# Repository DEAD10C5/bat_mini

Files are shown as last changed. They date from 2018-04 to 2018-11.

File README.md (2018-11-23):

# Bat Badge 2018  



## Serial

You can make a serial connection to the badge using a USB to TTL serial cable. 

For example: 
[USB to TTL Serial Cable](https://www.adafruit.com/product/954)

- Green wire: Connect to serial port, right side looking at back. 
- White wire: Connect to serial port, left side looking at back.
- Black wire: Connect to Battery port, negative (-) port. 
- Red/Orange wire: Do not connect! This is +5V but the board is at +3V. 

## Programming 

We used an Arduino UNO as an ISP to program the attiny84 chip on the badge. 

[Set up the programming environment](http://highlowtech.org/?p=1695)

We did a "6 way" header similar to the one described at the link below. 

[About ISP headers](http://www.batsocks.co.uk/readme/isp_headers.htm)

## Chip Information

ATMEL ATTINY84 / ARDUINO pinout

````
//

//                      +-\/-+

//                VCC 1|      |14 GND

//       `  (D 0) PB0 2|      |13 AREF (D10)

//          (D 1) PB1 3|      |12 PA1 (D9) 

//                PB3 4|      |11 PA2 (D 8) 

// PWM INT0 (D 2) PB2 5|      |10 PA3 (D 7) 

//      PWM (D 3) PA7 6|      |9 PA4(D 6) 

//      PWM (D 4) PA6 7|      |8 PA5(D 5) PWM

//                      +----+

IDE Attiny84 Physical Pin  Usage
  0      PA0           13  Button
  1      PA1           12  Heart
  2      PA2           11  RGB LED Data Pin
  3      PA3           10  Serial TX
  4      PA4            9
  5      PA5            8  Left Eye
  6      PA6            7  Right Eye
  7      PA7            6
  8      PB2            5
  9      PB1            3  Serial RX 
 10      PB0            2     
```

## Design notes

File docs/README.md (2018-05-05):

* http://42bots.com/tutorials/programming-attiny84-attiny44-with-arduino-uno/

# power

https://www.sparkfun.com/products/11892
https://www.sparkfun.com/products/10860

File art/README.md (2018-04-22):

# wipe the outline layer

display none 200;
group all;
delete (>0 0);
display last;
layer -200;

# import artwork

* scale art  0.0625 MM

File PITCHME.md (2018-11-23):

# Badge Workshop`

Tales From the Workbench

---

### 

- Dispatcher: Manages Data Flow
- Stores: Handle State & Logic
- Views: Render Data via React

---

Flux Explained

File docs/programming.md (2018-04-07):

* Connect a 10 uF capacitor between “Reset” and “Ground” pins on the Arduino Uno board as shown in the diagram. The stripe of the capacitor with the negative sign (“-”) goes to the Arduino “Ground” pin. This prevents the Arduino Uno from resetting and ensures that the Arduino IDE talks to the ArduinoISP (and not the bootloader) during the upload of the sketches to the ATTiny.
* Connect the ATtiny84/44 Pin 1 (with the little dot) to the 5 volt breadboard rail.
* Connect the ATtiny84/44 Pin 14 to ground.
* RESET: Connect the ATtiny84/44 Pin 4 (Reset) to Arduino Pin 10.
* MOSI: Connect the ATtiny84/44 Pin 7  to Arduino Pin 11.
* MISO: Connect the ATtiny84/44 Pin 8 to Arduino Pin 12.
* CLOCK: Connect the ATTiny84/44 Pin 9 to Arduino Pin 13
* Connect the ground and 5v from the Arduino to the breadboard.

Make sure you select the option “ATTiny84  (internal 1 MHz clock)”, or “ATTiny44  (internal 1 MHz clock)” in the Tools->Board menu (depending on which version of the chip you have):

Upload the sketch using the “File” -> “Upload Using Programmer” command (Ctrl + Shift + U).

If you get an error like this: “avrdude: please define PAGEL and BS2 signals in the configuration file…”, you can safely ignore it. This relate to parallel programmers and is not an issue here.

If all works well, you should have a blinking LED and a proven method for uploading Arduino sketches to your ATTiny84/44. Congratulations!

The next step  (Step 6) is optional. By default, the ATTiny chips run at 1 MHz. You need an extra step to configure the microcontroller to run at 8 MHz. This is a requirement for using some popular Arduino libraries, as well as to take full advantage of your chip.

To do so, you need to use the same wiring that you used to upload the blink sketch in the previous step. Under “Tools”->”Board” menu, this time select the option “ATtiny84 (internal 8 Mhz clock)”, or  “ATtiny44 (internal 8 Mhz clock)”, depending on which chip you have. It is important to pick the correct clock speed from the menu. Choosing the 20 Mhz external clock option, will require you to add wire in a 20 MHz crystal, or resonator, in order to program and use your ATTiny84/44.

Next, again under the “Tools” menu, choose the option “Burn Bootloader”. There is actually, no bootloader on the ATTiny chips, but this step will set the fuses to the values that will allow it to run at 8 Mhz, similarly to what we did for the ATtiny85 in the previous write-up.

Again, ignore any errors related to PAGEL and BS2 signals you may get. To make sure the change worked, you may want to re-upload the modified Blink sketch from step 5, this time using the internal 8 MHz clock option for your chip from the Boards menu.

Next, time to use the ATTiny in a real project! A warning: not all Arduino libraries will work on the ATTiny chips. The Arduino forum is a great place to search for additional info, if you run into issues. Chances are, someone already had this problem and found a solution.

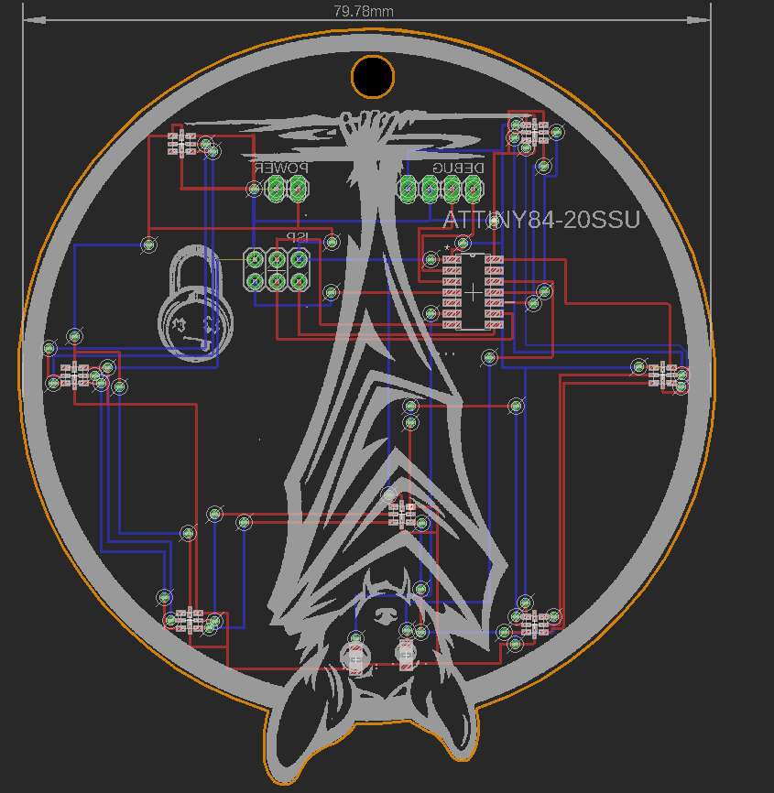
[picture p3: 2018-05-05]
art/Screenshot1.png

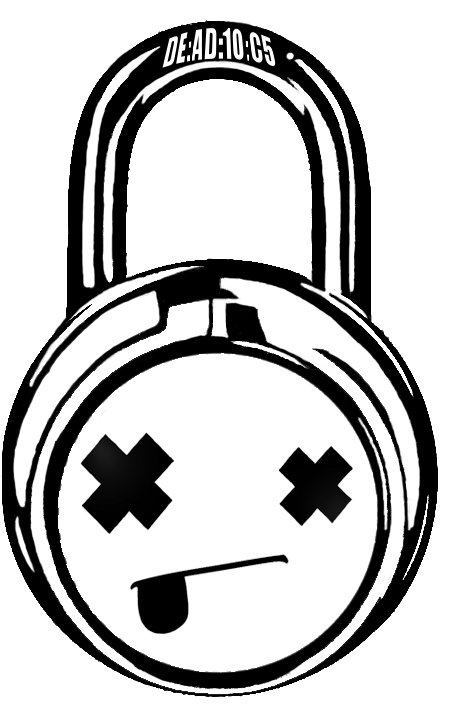
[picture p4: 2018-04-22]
art/DE:AD:10:C5-2.bmp

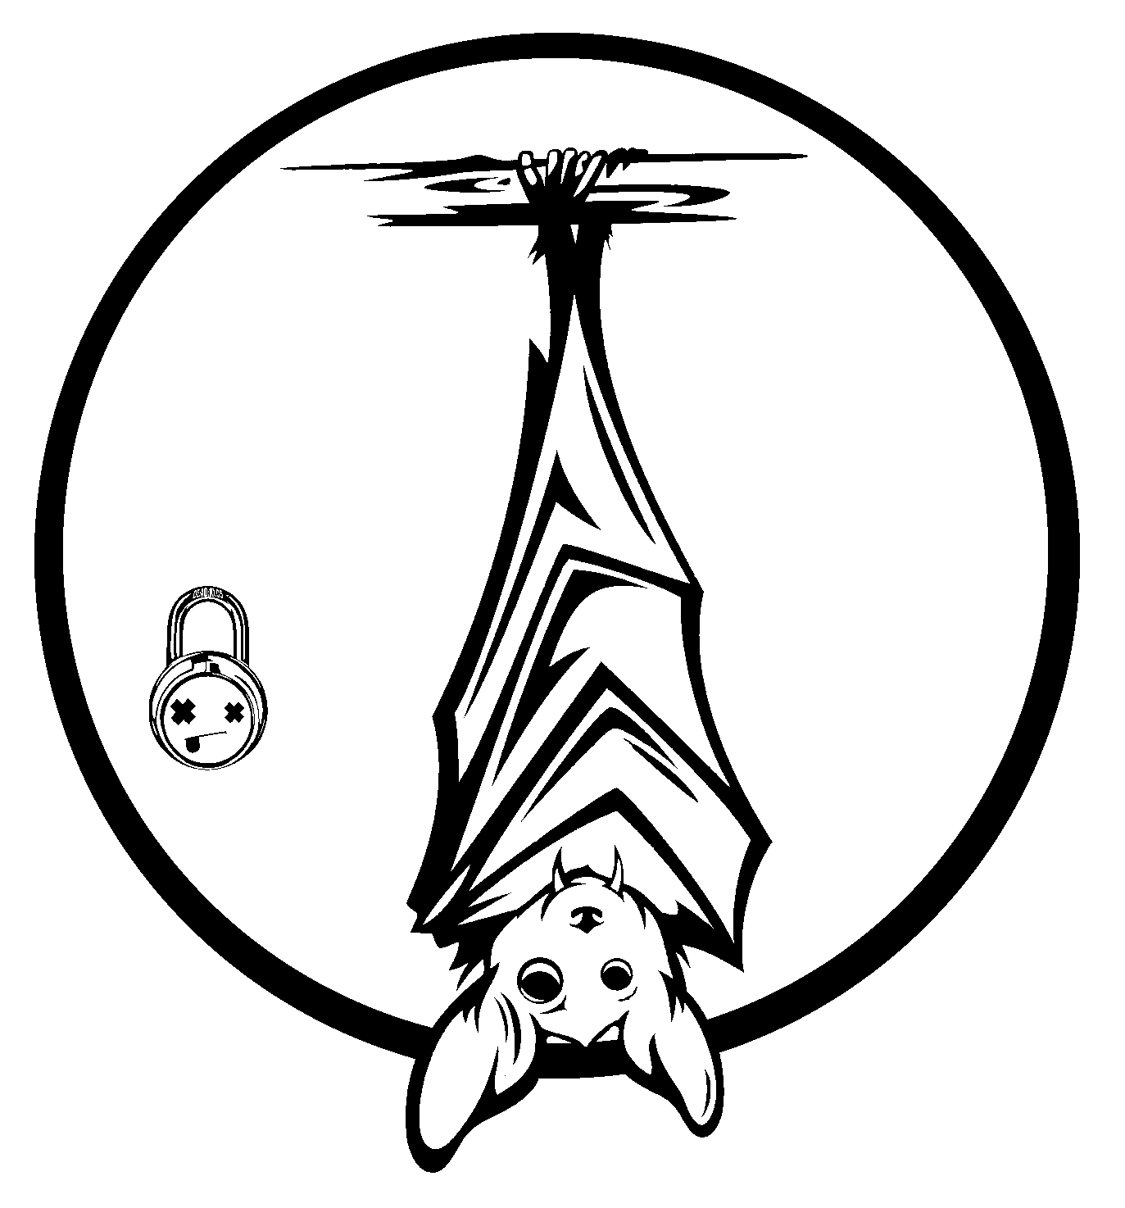
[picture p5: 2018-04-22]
art/bat_8bit_innerNEW.bmp

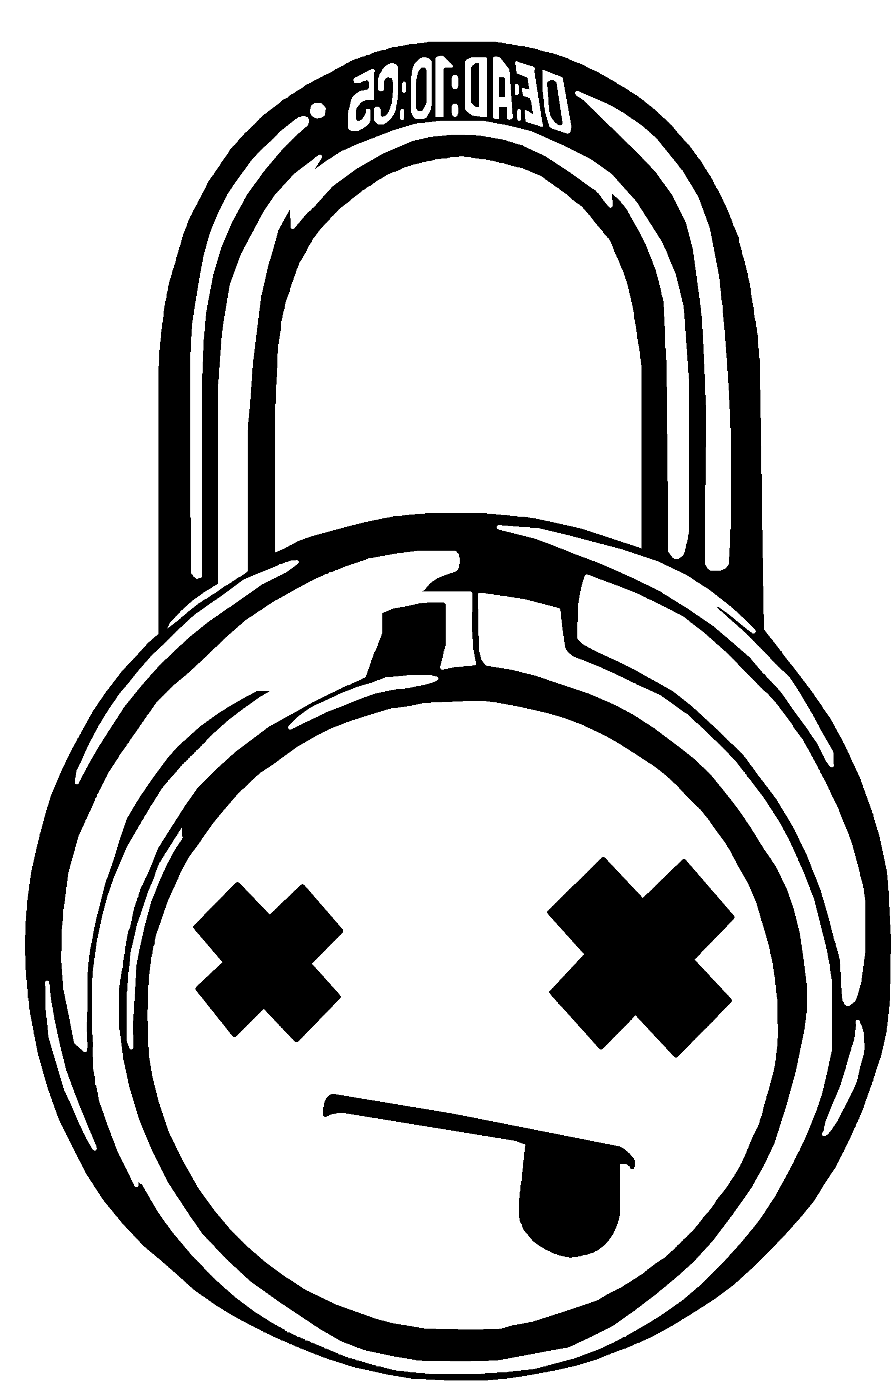
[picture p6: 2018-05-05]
art/lock_NEW_flipped.bmp

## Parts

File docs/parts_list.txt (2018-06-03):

Partlist

Exported from bat_mini4.brd at 5/18/18 10:08 PM

EAGLE Version 9.0.1 Copyright (c) 1988-2018 Autodesk, Inc.

Assembly variant: 

Part     Value          Package             Library                       Position (mm)         Orientation

.        .              CHIP-LED0805        led                           (47.0725 17.485)      R0
..       ..             CHIP-LED0805        led                           (41.26 16.9225)       R0
...      ATTINY84-20SSU SOIC127P600X175-14N Atmel_By_element14_Batch_1-00 (54.845 59.625)       R0
BT1                     BATTCON_20MM_4LEGS  SF_Batteries                  (24.375 38.5625)      MR0
BT2                     BATTCON_20MM_4LEGS  SF_Batteries                  (63.1875 37.25)       MR0
DEBUG                   1X04                pinhead                       (51.0725 71.5475)     MR0
ISP      .              2X03                pinhead                       (32.0725 62.1725)     MR0
ONE      APA102         APA102-2020         pimoroni-optoelectronics      (62.01 78.1725)       R0
THREE    APA102         APA102-2020         pimoroni-optoelectronics      (62.01 20.985)        R0
TWO      APA102         APA102-2020         pimoroni-optoelectronics      (76.8225 49.985)      R0
U$5      APA102         APA102-2020         pimoroni-optoelectronics      (46.5925 33.7825)     R0
U$6      APA102         APA102-2020         pimoroni-optoelectronics      (21.9475 21.485)      R0
U$7      APA102         APA102-2020         pimoroni-optoelectronics      (8.5725 49.9225)      R0
U$8      APA102         APA102-2020         pimoroni-optoelectronics      (21.01 76.86)         R0

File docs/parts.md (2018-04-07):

https://lighthouseleds.com/led-component-lighting/smd-leds-surface-mount-diodes/0805-smd-led.html

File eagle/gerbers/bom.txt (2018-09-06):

Partlist

Exported from bat_mini_drby_2018.brd at 9/6/18 1:04 PM

EAGLE Version 9.1.2 Copyright (c) 1988-2018 Autodesk, Inc.

Assembly variant: 

Part      Value          Package             Library                       Position (mm)         Orientation

...       ATTINY84-20SSU SOIC127P600X175-14N Atmel_By_element14_Batch_1-00 (54.845 59.625)       R0
BATT      BATT           1X02                pinhead                       (66.225 50.26875)     MR0
BT1       CR2032         BATTCON_20MM_4LEGS  SF_Batteries                  (24.375 38.5625)      MR0
HEART     0805           CHIP-LED0805        led                           (46.9725 34.06625)    R0
ISP       .              2X03                pinhead                       (32.0725 62.1725)     MR0
LEFT_EYE  0805           CHIP-LED0805        led                           (41.26 16.9225)       R0
R1        470?           R0805               resistor                      (22.23125 70.5)       R0
RIGHT_EYE 0805           CHIP-LED0805        led                           (47.1375 17.65625)    R0
S1        omron          B3F-10XX            switch-omron                  (31.9125 70.5875)     MR180
SERIAL    pinhead 1x02   1X02                pinhead                       (52.675 72.21875)     MR0
U$4       APA102         APA102-2020         pimoroni-optoelectronics      (62.71875 77.38125)   R0
U$8       APA102         APA102-2020         pimoroni-optoelectronics      (76.44375 49.95625)   R0
U$9       APA102         APA102-2020         pimoroni-optoelectronics      (62.5875 22.8875)     R0
U$10      APA102         APA102-2020         pimoroni-optoelectronics      (23.1625 22.125)      R0
U$11      APA102         APA102-2020         pimoroni-optoelectronics      (8.2875 50.2)         R0
U$12      APA102         APA102-2020         pimoroni-optoelectronics      (22.175 77.45)        R0

We would like PCBWAY to add the following surface mount components to the front of the board:

ATTINY84-20SSU SOIC127P600X175-14N
HEART 0805 CHIP-LED0805 754-1133-1-ND APT2012SURCK  RED
R1   470 ohm          R0805      (RES SMD 470 OHM 5% 1/8W )

LEFT_EYE  0805           CHIP-LED0805 (yellow or orange) 754-1134-1-ND
APT2012SYCK 
RIGHT_EYE 0805           CHIP-LED0805   (yellow or orange) 754-1134-1-ND
APT2012SYCK 

http://www.led-color.com/upload/201604/APA102-2020%20SMD%20LED.pdf
https://www.aliexpress.com/item/50-1000Pcs-pack-DotStar-Micro-LEDs-APA102-2020-Smart-SMD-RGB-LED-APA102-2020-LED-Matrix/32852025779.html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,searchweb201602_2_10065_10068_10130_5015318_10547_10546_10059_10548_10545_10696_100031_5015220_10084_10083_10103_451_10618_452_10307_5016018_5015920,searchweb201603_16,ppcSwitch_5&algo_expid=0db12eb9-bf3c-4f67-bcf7-50f50c5f2bff-2&algo_pvid=0db12eb9-bf3c-4f67-bcf7-50f50c5f2bff&priceBeautifyAB=0
U$4       APA102         APA102-2020 
U$8       APA102         APA102-2020
U$9       APA102         APA102-2020
U$10      APA102         APA102-2020 
U$11      APA102         APA102-2020 
U$12      APA102         APA102-2020

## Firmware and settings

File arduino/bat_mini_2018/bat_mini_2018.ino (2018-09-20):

/*!
   @file hardware_test.ino
    ____  _____      _    ____    _  ___     ____ ____
   |  _ \| ____|_   / \  |  _ \ _/ |/ _ \ _ / ___| ___|
   | | | |  _| (_) / _ \ | | | (_) | | | (_) |   |___ \
   | |_| | |___ _ / ___ \| |_| |_| | |_| |_| |___ ___) |
   |____/|_____(_)_/   \_\____/(_)_|\___/(_)\____|____/


   Author : @dead10c5 @p0lr_ @mzbat @theDevilsVoice
   Date   : September 20th, 2018
   Version: 1.2
*/
#include "bat_mini.h"

SoftwareSerial Serial(RX, TX);

MyBat mybat;

APA102<DATA_PIN, CLOCK_PIN> ledStrip;

rgb_color colors[LED_COUNT];

long heartBeatArray[] = {
  50, 100, 15, 1200
};
int hbeatIndex = 1;   // this initialization is important or it starts on the "wrong foot"
long prevMillis;

/*
   (pin, intensity 0 (off) to 255 (max) )
*/
void eyes() {
  for (int i = -255; i <= 254; i++) {
    analogWrite(LEFT_EYE, abs(i));
    analogWrite(RIGHT_EYE, abs(i));
    delay(1);
  }
} // eyes()



void heartBeat(float tempo) {


  if ((millis() - prevMillis) > (long)(heartBeatArray[hbeatIndex] * tempo)) {
    hbeatIndex++;
    if (hbeatIndex > 3) hbeatIndex = 0;

    if ((hbeatIndex % 2) == 0) {
      digitalWrite(HEART, HIGH);
      delay((int)heartBeatArray[hbeatIndex]) ;
      digitalWrite(HEART, LOW);
      delay(150);
      digitalWrite(HEART, HIGH);
      delay((int)heartBeatArray[hbeatIndex]) ;
      digitalWrite(HEART, LOW);
    }
    hbeatIndex++;
    Serial.println(hbeatIndex);
    prevMillis = millis();

  }

}

void darkness() {

  // turn off the rgb leds
  for (uint16_t i = 0; i < LED_COUNT; i++) {
    colors[i] = mybat.hsvToRgb(0, 0, 0);
  }
  ledStrip.write(colors, LED_COUNT, 0);

  // turn off other LEDs
  digitalWrite(LEFT_EYE, LOW);
  digitalWrite(RIGHT_EYE, LOW);
  digitalWrite(HEART, LOW);

} // darkness()

void rainbow() {

  mybat.buttonState = HIGH;
  delay(100);

  while (mybat.buttonState != LOW) {

    uint8_t time = millis() >> 4;
    for (uint16_t i = 0; i < LED_COUNT; i++) {
      uint8_t p = time - i * 8;
      colors[i] = mybat.hsvToRgb((uint32_t)p * 359 / 256, 255, 255);
    }
    ledStrip.write(colors, LED_COUNT, BRIGHTNESS);
    delay(100);

    mybat.buttonState = digitalRead(1);
  }

} //rainbow()

void flicker() {

  mybat.buttonState = HIGH;
  delay(100);

  while (mybat.buttonState != LOW) {


    // pulse the eyes all the time
    eyes();

    //heartbeat();
    heartBeat(1.0);

    uint8_t time = millis() >> 4;
    for (uint16_t i = 0; i < LED_COUNT; i++) {
      uint8_t p = time - i * 8;
      colors[i] = mybat.hsvToRgb((uint32_t)p * 359 / 256, 255, 255);
    }
    ledStrip.write(colors, LED_COUNT, BRIGHTNESS);
    delay(100);

    mybat.buttonState = digitalRead(1);
  }
} // flicker()


void sin_wave() {

  mybat.buttonState = HIGH;
  delay(100);
  float tcount = 0.0;
  int ibright = 0;
  int ihue = random(0, 255);
  while (mybat.buttonState != LOW) {

    // pulse the eyes all the time
    eyes();

    heartBeat(0.5);

    for (int i = 0; i < LED_COUNT; i++ ) {
      tcount = tcount + .1;
      if (tcount > 3.14) {
        tcount = 0.0;
      }
      ibright = int(sin(tcount) * 255);
      colors[i] = mybat.hsvToRgb(ihue, 255, 255);
      ledStrip.write(colors, LED_COUNT, ibright);
      delay(100);
    }

    ledStrip.write(colors, LED_COUNT, 10);
    delay(100);
    mybat.buttonState = digitalRead(1);
  }
} // sin_wave()

void color_pop() {

  mybat.buttonState = HIGH;
  delay(100);

  int idex = random(0, LED_COUNT);
  int ihue = random(0, 255);

  while (mybat.buttonState != LOW) {
    // pulse the eyes all the time
    eyes();
    heartBeat(0.5);
    colors[idex] = mybat.hsvToRgb(ihue, 255, 255);
    ledStrip.write(colors, LED_COUNT, BRIGHTNESS);
    delay(100);
    idex = random(0, LED_COUNT);
    ihue = random(0, 255);
    mybat.buttonState = digitalRead(1);
  }
} // color_pop()

void cyber_police() {

  mybat.buttonState = HIGH;
  delay(100);
  while (mybat.buttonState != LOW) {
    // pulse the eyes all the time
    eyes();
    heartBeat(0.5);
    for (uint16_t i = 0; i < LED_COUNT; i++)
    {
      if (i % 2 == 0) {
        //uint8_t x = time - i * 8;
        colors[i].red = 0;
        colors[i].green = 0;
        colors[i].blue = 255;
      } else {
        colors[i].red = 0;
        colors[i].green = 255;
        colors[i].blue = 0;
      }

    }
    ledStrip.write(colors, LED_COUNT, 10);
    mybat.buttonState = digitalRead(1);
    delay(100);
    // pulse the eyes all the time
    eyes();
    heartBeat(0.5);
    for (uint16_t i = 0; i < LED_COUNT; i++)
      if (i % 2 != 0) {
        //uint8_t x = time - i * 8;
        colors[i].red = 0;
        colors[i].green = 0;
        colors[i].blue = 255;
      } else {
        colors[i].red = 0;
        colors[i].green = 255;
        colors[i].blue = 0;
      }
    ledStrip.write(colors, LED_COUNT, 5);
    mybat.buttonState = digitalRead(1);
    delay(100);
  }
} //cyber_police()

void led_only() {

  mybat.buttonState = HIGH;
  delay(100);

  while (mybat.buttonState != LOW) {
    // pulse the eyes all the time
    eyes();
    heartBeat(0.5);
    delay(100);
    mybat.buttonState = digitalRead(1);
  }

} //led_only()

void setup() {
  Serial.begin(9600);
  Serial.println("##############################");
  Serial.println("# DE:AD:10:C5 Bat Badge 2018 #");
  Serial.println("##############################");
  Serial.println("This badge was a lot of work and a lot of fun. Hope you enjoy it!");
  Serial.println("...");
  Serial.print("Version: ");
  Serial.println(VERSION);
  Serial.println("Initializing...");
  pinMode(LEFT_EYE, OUTPUT);
  pinMode(RIGHT_EYE, OUTPUT);
  pinMode(HEART, OUTPUT);
  pinMode(BUTTON, INPUT);
  mybat.buttonState = LOW;
  mybat.led_pattern_cur = 1;
  Serial.println("Complete!");
}

void loop() {

  Serial.println("Time to make a selection...");

  if (mybat.buttonState == LOW) {
    switch (mybat.led_pattern_cur) {
      case 1:
        flicker();
        darkness();
        mybat.led_pattern_cur++;
        break;
      case 2:
        sin_wave();
        darkness();
        mybat.led_pattern_cur++;
        break;
      case 3:
        color_pop();
        darkness();
        mybat.led_pattern_cur++;
        break;
      case 4:
        rainbow();
        darkness();
        mybat.led_pattern_cur++;
        break;
      case 5:
        cyber_police();
        darkness();
        mybat.led_pattern_cur++;
        break;
      case 6:
        led_only();
        mybat.led_pattern_cur = 1; // button push takes us back to the first pattern
        break;
      default:
        break;
    }
  }
}

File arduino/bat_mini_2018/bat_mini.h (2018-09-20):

/*!
   @file bat_mini.h
    ____  _____      _    ____    _  ___     ____ ____
   |  _ \| ____|_   / \  |  _ \ _/ |/ _ \ _ / ___| ___|
   | | | |  _| (_) / _ \ | | | (_) | | | (_) |   |___ \
   | |_| | |___ _ / ___ \| |_| |_| | |_| |_| |___ ___) |
   |____/|_____(_)_/   \_\____/(_)_|\___/(_)\____|____/


   Author : @p0lr_ @mzbat @theDevilsVoice @dead10c5
   Date   : September 20th, 2018
   Version: 1.2

                    ATMEL ATTINY84 / ARDUINO

                             +-\/-+
                       VCC  1|    |14  GND
               (D  0)  PB0  2|    |13  AREF (D 10)
               (D  1)  PB1  3|    |12  PA1  (D  9)
                       PB3  4|    |11  PA2  (D  8)
    PWM  INT0  (D  2)  PB2  5|    |10  PA3  (D  7)
    PWM        (D  3)  PA7  6|    |9   PA4  (D  6)
    PWM        (D  4)  PA6  7|    |8   PA5  (D  5)        PWM
                             +----+

IDE Attiny84 Physical Pin
  0      PA0           13
  1      PA1           12
  2      PA2           11
  3      PA3           10
  4      PA4            9
  5      PA5            8
  6      PA6            7
  7      PA7            6
  8      PB2            5
  9      PB1            3
 10      PB0            2

*/
#ifndef BAT_H
#define BAT_H

#define VERSION "1.2"
#define LEDBLINK_MS     1000  // Blink rate (in milliseconds)

#include <Arduino.h>
#include <APA102.h>
#include <SoftwareSerial.h>

// ***
// *** Define the RX and TX pins. Choose any two
// *** pins that are unused. Try to avoid D0 (pin 5)
// *** and D2 (pin 7) if you plan to use I2C.
// ***
#define RX    3
#define TX    10

/*
 *     
 *  3V3/5V - This wire is optional and can be used to power your circuit during testing. You can power your circuit only when the 
 *  current demand is limited (less than 500 mA). This wire is usually red (color may be vary).
    GND - This wire is required and should be connected to pin 4 on the ATtiny85 (or to whatever point you designated as ground). 
    This wire is usually black (color may be vary).
    TX - This wire is used by the external device to send data to your ATtiny85. This wire should be connected to the pin you 
    designated as RX when you setup your Software Serial instance. On FTDI cables, this wire is usually orange. On the USB to TTL 
    Serial Cable this wire is usually green (color may be vary).
    RX - This wire is used by the external device to receive data from your ATtiny85. This wire should be connected to the pin 
    you designated as TX when you setup your Software Serial instance. On FTDI cables, this wire is usually yellow. On the USB 
    to TTL Serial Cable this wire is usually white (color may be vary).
 */

// pins'n'stuff
const uint8_t  DATA_PIN   = PA2;
const uint8_t  CLOCK_PIN  = PA3;
const uint8_t  RIGHT_EYE  = 7;
const uint8_t  LEFT_EYE   = 8;
const uint8_t  HEART      = 0;
const uint8_t  BUTTON     = 1;
const uint16_t LED_COUNT  = 6;
const uint8_t  BRIGHTNESS = 1;


class MyBat {
  public:
    int buttonState;         // variable for reading the pushbutton status
    uint8_t led_pattern_cur;
    
    rgb_color hsvToRgb(uint16_t, uint8_t, uint8_t);
};

#endif

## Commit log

2018-04-22 post proto updates
    [bat_mini1.brd, bat_mini2.brd, bat_mini2.sch]
2018-05-05 coin cells & fix routing
    [bat_mini3.brd, bat_mini3.sch, bat_mini4.sch]
2018-07-04 checkpoint brd 7
    [bat_mini1.GBL, bat_mini1.GBO, bat_mini1.GBP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]
2018-07-04 updated hardware test code
    [bat_mini5.GBL, bat_mini5.GBO, bat_mini5.GBP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]
2018-07-10 final pcb
    [bat_mini1.brd, bat_mini1.sch, bat_mini2.brd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]
2018-09-06 grrcon 2018
    [bat_mini6.sch, bat_mini8_defcon.brd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]
2018-09-06 updated sch, brd, and gerbers
    [bat_mini_drby_2018.GBL, bat_mini_drby_2018.GBO, bat_mini_drby_2018.GBP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]
2018-09-08 change derby boards
    [bat_mini_drby_viii.sch]
